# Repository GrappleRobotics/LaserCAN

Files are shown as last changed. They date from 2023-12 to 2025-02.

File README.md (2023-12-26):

# Grapple LaserCAN
Welcome to the open-source repository for the Grapple LaserCAN! That's right, everything's open source from the board files to the firmware.

**[Buy Here](https://grapplerobotics.au/)**

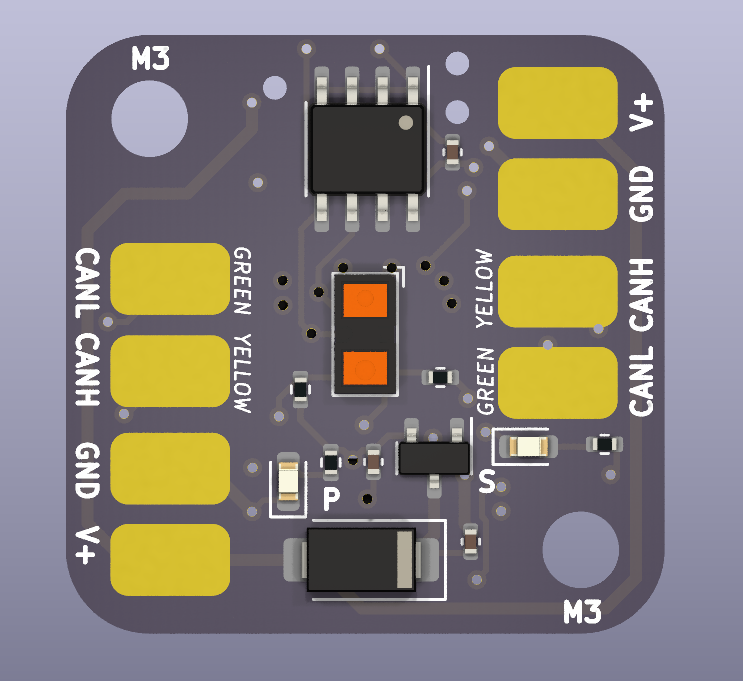
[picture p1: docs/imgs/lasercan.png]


## [Looking for docs?](docs/getting-started.md)

## Project Directories
- [LaserCAN-Board](LaserCAN-Board) is the KiCAD project that contains the LaserCAN board files. 
- [lasercan-common](lasercan-common) are common libraries used between the firmware and bootloader.
- [lasercan-bootloader](lasercan-bootloader) is the CAN bootloader for the LaserCAN, written in Rust. The bootloader allows for over-the-air (or over-the-CAN, rather) firmware updates.
- [lasercan-firmware](lasercan-firmware) is the actual firmware for the LaserCAN, including sensor measurement and acquisition, CAN communication, and everything else it does!

## Loading your own firmware
If you want to load your own firmware onto the LaserCAN, clone this repository and make your changes to `lasercan-firmware`. You can flash this image to the board by running `python build.py firmware` and flashing the `target/lasercan-firmware-update-VERSION.grplfw` file using GrappleHook.
**NOTE: Be careful about what firmware you flash - custom firmware may brick the firmware update process if you don't have a ST-Link probe handy.**

## Flashing a new bootloader
If you for whatever reason need to flash a new bootloader, or if a custom firmware has crashed and the watchdog hasn't picked it up, you can flash a new bootloader and firmware by running `python build.py flash`. This requires an ST-Link v2 compatible probe and a TagConnect TC-2050-NL cable to connect to the debug pads on the bottom of the LaserCAN.

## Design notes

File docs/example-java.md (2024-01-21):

# LaserCAN - FRC Example (Java)

## Install the Vendor Library:
In VSCode, hit CTRL+SHIFT+P and select "WPILib: Manage Vendor Libraries".  Select "Install new libraries (offline)" and paste the following URL: https://storage.googleapis.com/grapple-frc-maven/libgrapplefrc2024.json

## Use it!
```java
package frc.robot;

import au.grapplerobotics.LaserCan;
import au.grapplerobotics.ConfigurationFailedException;
import edu.wpi.first.wpilibj.TimedRobot;

public class Robot extends TimedRobot {
  private LaserCan lc;

  @Override
  public void robotInit() {
    lc = new LaserCan(0);
    // Optionally initialise the settings of the LaserCAN, if you haven't already done so in GrappleHook
    try {
      lc.setRangingMode(LaserCan.RangingMode.SHORT);
      lc.setRegionOfInterest(new LaserCan.RegionOfInterest(8, 8, 16, 16));
      lc.setTimingBudget(LaserCan.TimingBudget.TIMING_BUDGET_33MS);
    } catch (ConfigurationFailedException e) {
      System.out.println("Configuration failed! " + e);
    }
  }

  @Override
  public void robotPeriodic() {
    LaserCan.Measurement measurement = lc.getMeasurement();
    if (measurement != null && measurement.status == LaserCan.LASERCAN_STATUS_VALID_MEASUREMENT) {
      System.out.println("The target is " + measurement.distance_mm + "mm away!");
    } else {
      System.out.println("Oh no! The target is out of range, or we can't get a reliable measurement!");
      // You can still use distance_mm in here, if you're ok tolerating a clamped value or an unreliable measurement.
    }
  }

  @Override
  public void autonomousInit() {}

  @Override
  public void autonomousPeriodic() {}

  @Override
  public void teleopInit() {}

  @Override
  public void teleopPeriodic() {}

  @Override
  public void disabledInit() {}

  @Override
  public void disabledPeriodic() {}

  @Override
  public void testInit() {}

  @Override
  public void testPeriodic() {}
}
```

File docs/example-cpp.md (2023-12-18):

# LaserCAN - FRC Example (C++)

## Install the Vendor Library:
In VSCode, hit CTRL+SHIFT+P and select "WPILib: Manage Vendor Libraries".  Select "Install new libraries (offline)" and paste the following URL: https://storage.googleapis.com/grapple-frc-maven/libgrapplefrc2024.json

## Use it!
`Robot.h`

```c++
#pragma once

#include <frc/TimedRobot.h>
#include <grpl/LaserCan.h>

class Robot : public frc::TimedRobot {
 public:
  void RobotInit() override;
  void RobotPeriodic() override;

  void AutonomousInit() override;
  void AutonomousPeriodic() override;

  void TeleopInit() override;
  void TeleopPeriodic() override;

  void DisabledInit() override;
  void DisabledPeriodic() override;

  void TestInit() override;
  void TestPeriodic() override;
 private:
  grpl::LaserCan *lc;
};
```

`Robot.cpp`

```c++
#include "Robot.h"
#include <iostream>

void Robot::RobotInit() {
  lc = new grpl::LaserCan(0);
    // Optionally initialise the settings of the LaserCAN, if you haven't already done so in GrappleHook
  lc->set_ranging_mode(grpl::LaserCanRangingMode::Long);
  lc->set_timing_budget(grpl::LaserCanTimingBudget::TimingBudget100ms);
  lc->set_roi(grpl::LaserCanROI{ 8, 8, 16, 16 });
}

void Robot::RobotPeriodic() {
  std::optional<grpl::LaserCanMeasurement> measurement = lc->get_measurement();
  if (measurement.has_value() && measurement.value().status == grpl::LASERCAN_STATUS_VALID_MEASUREMENT) {
    std::cout << "The target is " << measurement.value().distance_mm << "mm away!" << std::endl;
  } else {
    std::cout << "Oh no! The target is out of range, or we can't get a reliable measurement!" << std::endl;
    // You can still use distance_mm in here, if you're ok tolerating a clamped value or an unreliable measurement.
  }
}

void Robot::AutonomousInit() {}
void Robot::AutonomousPeriodic() {}

void Robot::TeleopInit() {}
void Robot::TeleopPeriodic() {}

void Robot::DisabledInit() {}
void Robot::DisabledPeriodic() {}

void Robot::TestInit() {}
void Robot::TestPeriodic() {}

#ifndef RUNNING_FRC_TESTS
int main() {
  return frc::StartRobot<Robot>();
}
#endif

```

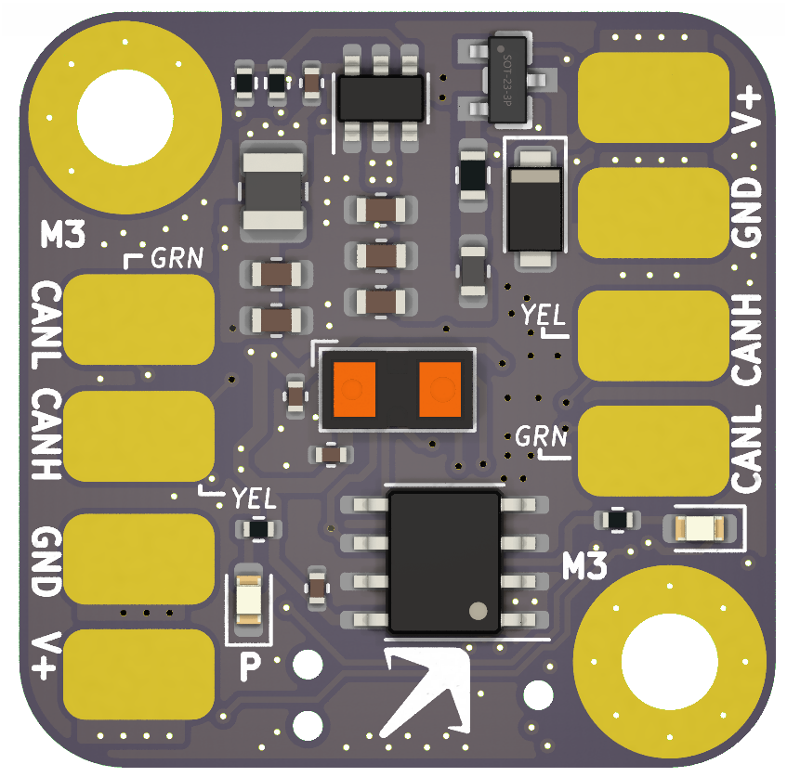
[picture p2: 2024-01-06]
docs/imgs/lasercan_rev4_transparent.png

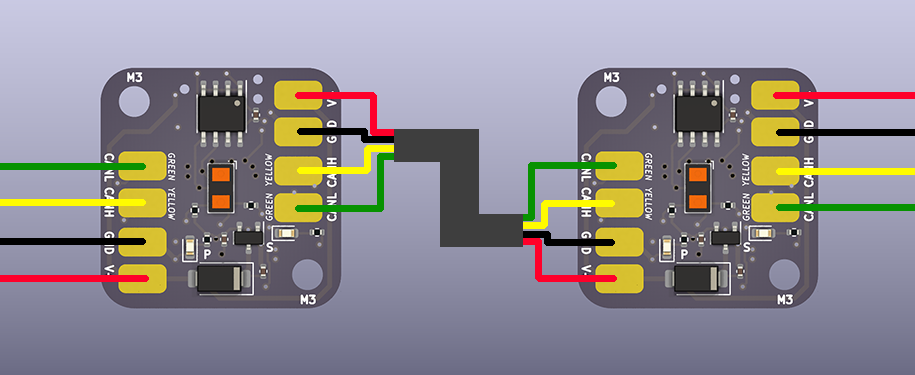
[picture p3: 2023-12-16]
docs/imgs/daisychain.png

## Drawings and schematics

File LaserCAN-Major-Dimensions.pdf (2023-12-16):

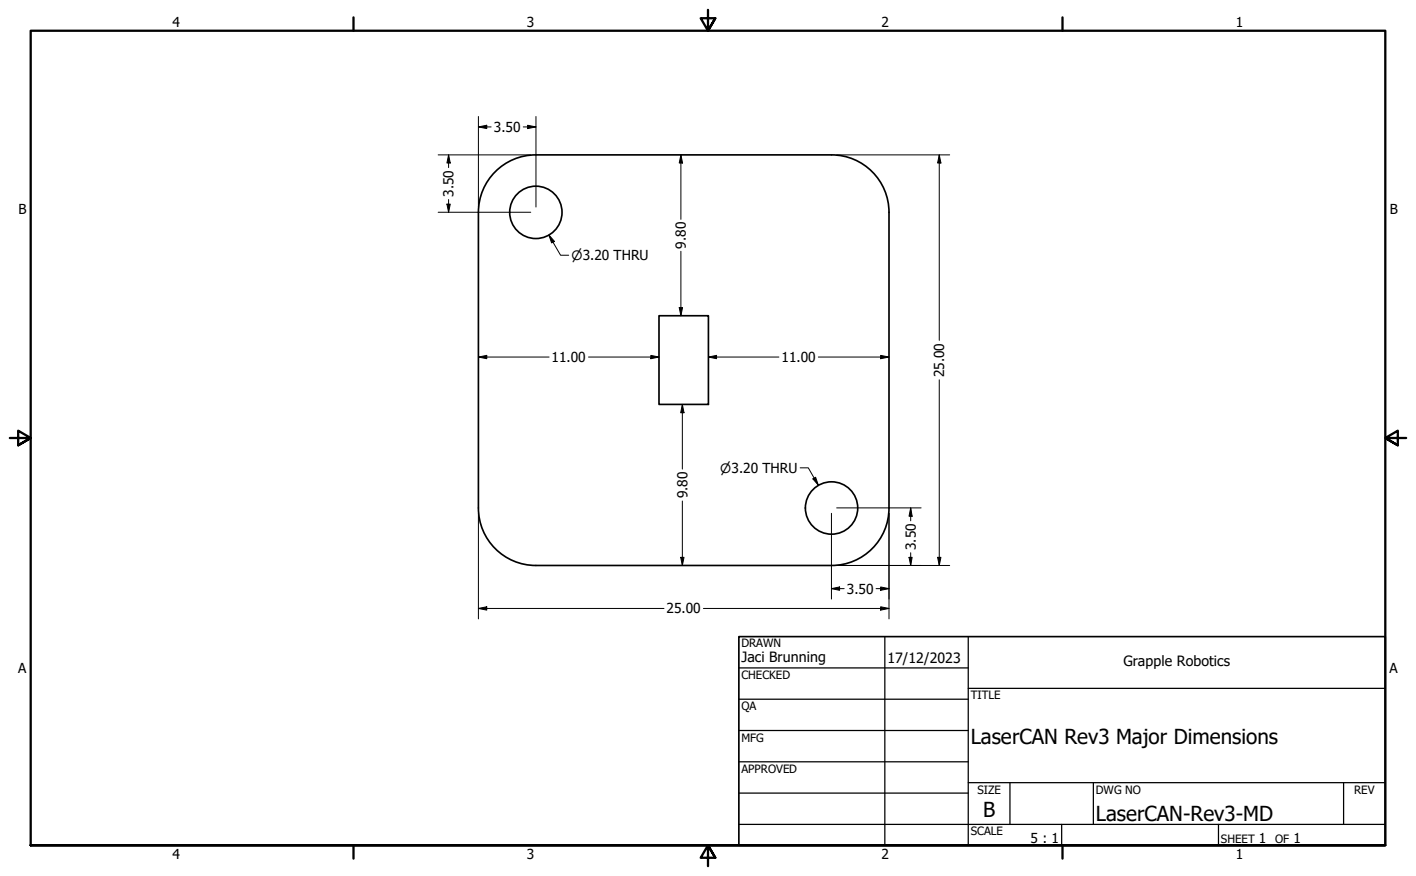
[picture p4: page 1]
⌀3.20 THRU

DRAWN Jaci Brunning | 17/12/2023 | Grapple Robotics

CHECKED

TITLE
LaserCAN Rev3 Major Dimensions

MFG

APPROVED

SIZE B | DWG NO LaserCAN-Rev3-MD | REV

SCALE 5 : 1 | | SHEET 1 OF 1

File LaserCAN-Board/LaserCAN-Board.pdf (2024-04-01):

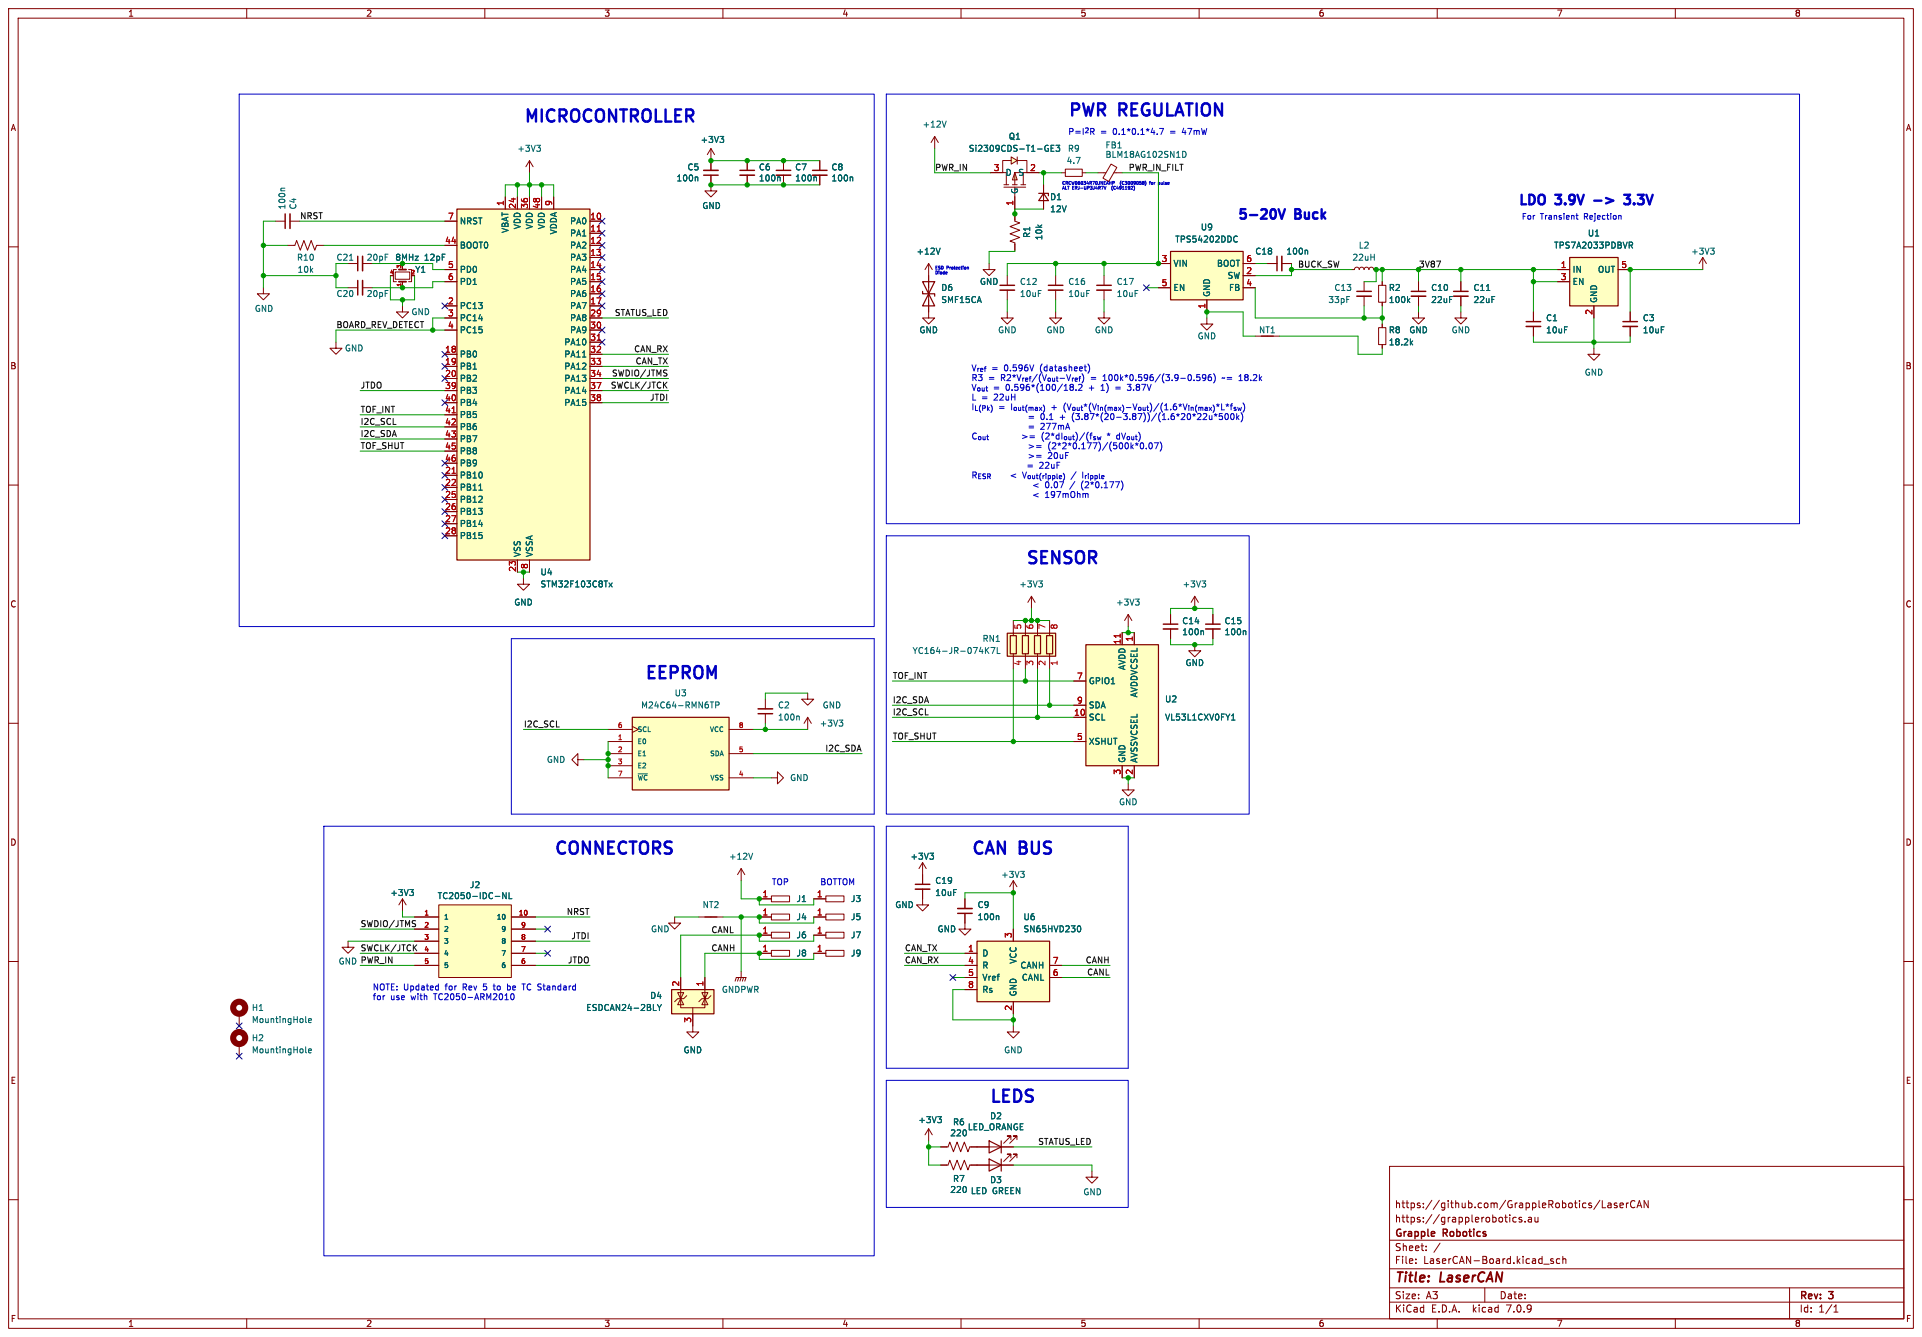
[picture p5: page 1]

For Transient Rejection CAN BUS

NOTE: Updated for Rev 5 to be TC Standard

https://github.com/GrappleRobotics/LaserCAN
https://grapplerobotics.au

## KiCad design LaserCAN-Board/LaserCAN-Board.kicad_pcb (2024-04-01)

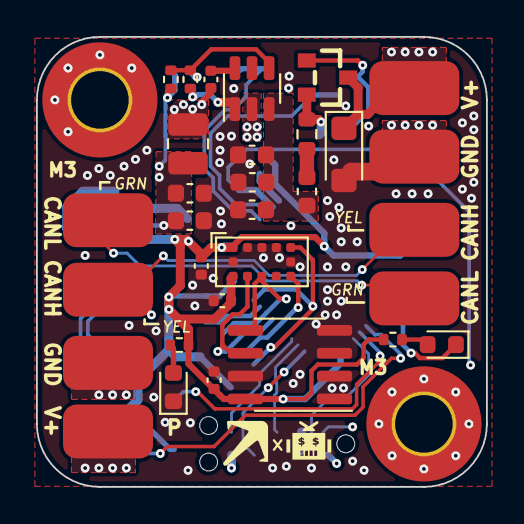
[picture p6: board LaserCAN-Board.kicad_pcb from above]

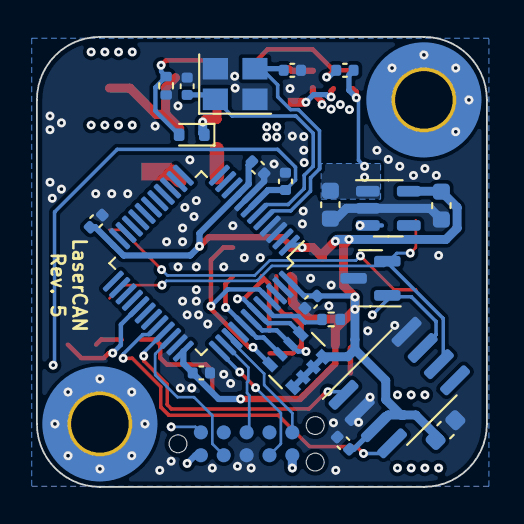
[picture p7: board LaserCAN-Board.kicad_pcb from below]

Board: 4 copper layers, 25.0 x 25.0 mm, 57 parts (22 on the bottom side), 32 nets.

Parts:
C1, C3, C12, C16, C17, C19: 10uF; C_0603_1608Metric
C2, C4, C5, C6, C7, C8, C9, C14, C15, C18: 100n; C_0402_1005Metric
C10, C11: 22uF; C_0603_1608Metric
C13: 33pF; C_0402_1005Metric
C20, C21: 20pF; C_0402_1005Metric
D1: 12V; D_SOD-523
D2: LED_ORANGE; LED_0603_1608Metric
D3: LED GREEN; LED_0603_1608Metric
D4: ESDCAN24-2BLY; SOT-23
D6: SMF15CA; D_SMF
FB1: BLM18AG102SN1D; L_0603_1608Metric
H1, H2: MountingHole; MountingHole_3.2mm_M3_Pad_TopBottom
J1, J3, J4, J5, J6, J7, J8, J9: Pad
J2: TC2050-IDC-NL; TAG-CONNECT_TC2050-IDC-NL
L2: 22uH; L_1008_2520Metric
NT1: NetTie_2; NetTie-2_SMD_Pad0.5mm
NT2: NetTie_2; NetTie-2_SMD_Pad2.0mm
Q1: Si2309CDS-T1-GE3; SOT-23_L2.9-W1.3-P1.90-LS2.4-BR
R1, R10: 10k; R_0402_1005Metric
R2: 100k; R_0402_1005Metric
R6, R7: 220; R_0402_1005Metric
R8: 18.2k; R_0402_1005Metric
R9: 4.7; R_0603_1608Metric
RN1: YC164-JR-074K7L; R_Array_Convex_4x0603
U1: TPS7A2033PDBVR; SOT-23-5
U2: VL53L1CXV0FY1; ST_VL53L1x
U3: M24C64-RMN6TP; SOIC-8_3.9x4.9mm_P1.27mm
U4: STM32F103C8Tx; LQFP-48_7x7mm_P0.5mm
U6: SN65HVD230; SOIC-8_3.9x4.9mm_P1.27mm
U9: TPS54202DDC; SOT-23-6
Y1: 8MHz 12pF; Crystal_SMD_3225-4Pin_3.2x2.5mm

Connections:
+3V3: C2.1, C3.1, C5.2, C6.1, C7.1, C8.1, C9.2, C14.1, C15.1, C19.1, J2.1, R6.1, R7.1, RN1.5 (R4.2), RN1.6 (R3.2), RN1.7 (R2.2), RN1.8 (R1.2), U1.5 (OUT), U2.1 (AVDDVCSEL), U2.11 (AVDD), U3.8 (VCC), U4.1 (VBAT), U4.9 (VDDA), U4.24 (VDD), U4.36 (VDD), U4.48 (VDD), U6.3 (VCC)
+12V: D6.1 (A1), J1.1, J2.5, J3.1, Q1.3 (D)
/3V87: C1.1, C10.1, C11.1, C13.1, L2.2, R2.1, U1.1 (IN), U1.3 (EN)
/BUCK_SW: C18.2, L2.1, U9.2 (SW)
/CANH: D4.1 (K), J8.1, J9.1, U6.7 (CANH)
/CANL: D4.2 (K), J6.1, J7.1, U6.6 (CANL)
/CAN_RX: U4.32 (PA11), U6.4 (R)
/CAN_TX: U4.33 (PA12), U6.1 (D)
/I2C_SCL: RN1.2 (R2.1), U2.10 (SCL), U3.6 (SCL), U4.42 (PB6)
/I2C_SDA: RN1.1 (R1.1), U2.9 (SDA), U3.5 (SDA), U4.43 (PB7)
/JTDI: J2.8, U4.38 (PA15)
/JTDO: J2.6, U4.39 (PB3)
/NRST: C4.2, J2.10, U4.7 (NRST)
/PWR_IN_FILT: C12.1, C16.1, C17.1, FB1.2, U9.3 (VIN)
/STATUS_LED: D2.1 (K), U4.29 (PA8)
/SWCLK/JTCK: J2.4, U4.37 (PA14)
/SWDIO/JTMS: J2.2, U4.34 (PA13)
/TOF_INT: RN1.3 (R3.1), U2.7 (GPIO1), U4.41 (PB5)
/TOF_SHUT: RN1.4 (R4.1), U2.5 (XSHUT), U4.45 (PB8)
GND: C1.2, C2.2, C3.2, C4.1, C5.1, C6.2, C7.2, C8.2, C9.1, C10.2, C11.2, C12.2, C14.2, C15.2, C16.2, C17.2, C19.2, C20.1, C21.1, D3.1 (K), D4.3 (A), D6.2 (A2), J2.3, NT1.2, NT2.1, R1.1, R10.1, U1.2 (GND), U2.2 (AVSSVCSEL), U2.3 (GND), U2.4 (GND), U2.6 (GND), U2.12 (GND), U3.1 (E0), U3.2 (E1), U3.3 (E2), U3.4 (VSS), U3.7 (~WC), U4.3 (PC14), U4.4 (PC15), U4.8 (VSSA), U4.23 (VSS), U4.35 (VSS), U4.47 (VSS), U6.2 (GND), U6.8 (Rs), U9.1 (GND), Y1.2, Y1.4
GNDPWR: J4.1, J5.1, NT2.2
unnamed: D1.2 (A), Q1.1 (G), R1.2
unnamed: D1.1 (K), Q1.2 (S), R9.1
unnamed: D2.2 (A), R6.2
unnamed: D3.2 (A), R7.2
unnamed: FB1.1, R9.2
unnamed: NT1.1, R8.2
unnamed: R10.2, U4.44 (BOOT0)
unnamed: C21.2, U4.5 (PD0), Y1.3
unnamed: C20.2, U4.6 (PD1), Y1.1
unnamed: C18.1, U9.6 (BOOT)
unnamed: C13.2, R2.2, R8.1, U9.4 (FB)

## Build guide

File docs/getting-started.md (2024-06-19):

# Getting Started with LaserCAN
Getting Started with LaserCAN is easy! Follow this guide and you'll be using your sensor in no time!

## 1. Connect Power
**IMPORTANT:** Double check the FRC Rule Manual for wire gauges, PDP/PDH output selection, etc.

### Direct
To wire up your LaserCAN, connect V+ to the 6V (PWM) or 5V (DIO) source on your RoboRIO, and GND to any Ground pin on the RoboRIO.

### Daisy-Chain
Alternatively, you can power the LaserCAN from another LaserCAN by connecting the V+ pads together, and likewise for the GND pads. **DO NOT** Daisy-Chain more than 8 LaserCANs in one chain!

## 2. Connect CAN
Next, connect the CANH and CANL pads of the LaserCAN to your robot's CAN bus. This can be done in one of three ways:

### Pass-Through
Insert the LaserCAN in an existing CAN line by connecting both sides of the LaserCAN's CAN pads, "passing through" the connection to downstream devices.

### Star
Alternatively, branch off from an existing CAN connection, forming a new branch that can be connected to one side of the LaserCAN. If connecting in this manner, ensure the stub length is short (i.e. a short branch).

### Star + Pass-Through
If you have more than one LaserCAN, you can use the Star method to connect the first LaserCAN, and connect the rest through passthrough, starting at the first LaserCAN's unoccupied pads. Ensure the total stub length is also short, less than 2 meters for 1Mbps CAN 2.0B.

## 3. Power on your LaserCAN
Power on your robot to power on the LaserCAN. The orange LED should blink rapidly for 2-3 seconds before turning off. If the orange LED remains on, your LaserCAN may require a firmware update.

## 4. Download and Install GrappleHook
Download the latest version of GrappleHook for your platform here: https://github.com/GrappleRobotics/GrappleHook/releases

*Tip: If you're on windows, select the asset ending in .msi*

## 5. Run GrappleHook
Connect your RoboRIO over a USB cable, and open GrappleHook. Select RoboRIO, and hit "Connect"

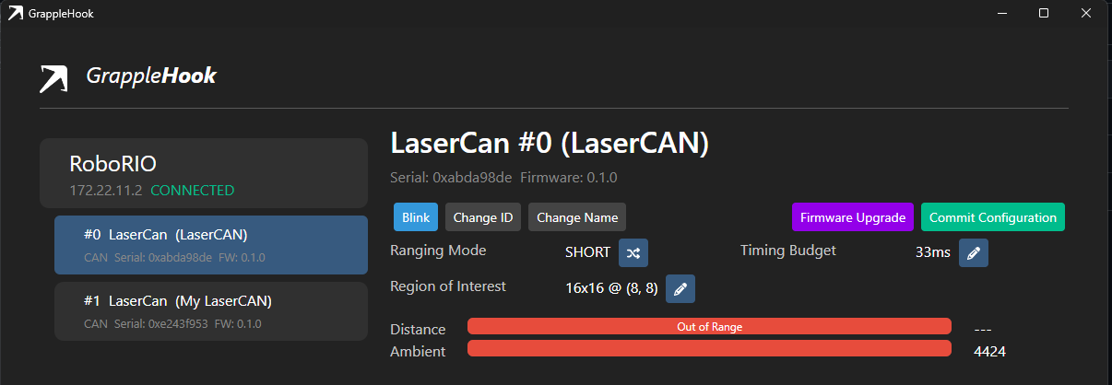
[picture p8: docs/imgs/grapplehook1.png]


## 6. Set the CAN ID
In GrappleHook, select "Change ID" and set a new CAN ID for your LaserCAN. Choose something unique from other LaserCANs, otherwise they'll conflict!

## 7. Install the libgrapplefrc Vendor Library
In VSCode, hit CTRL+SHIFT+P and select "WPILib: Manage Vendor Libraries".  Select "Install new libraries (online)" and paste the following URL: https://storage.googleapis.com/grapple-frc-maven/libgrapplefrc2024.json

## 8. Use LaserCAN!
See one of our examples: 
- [Java](example-java.md)
- [C++](example-cpp.md)

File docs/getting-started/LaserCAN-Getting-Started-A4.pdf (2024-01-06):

# Getting Started with LaserCAN

# 1. Remove Protective Film

Remove the protective fi lm from the laser sensor in the centre of the LaserCAN.

# 2. Connect Power

While your robot is powered o , wire the V+ and GND to RoboRIO 5V or 6V rails, found on the PWM and DIO headers, or to the PDP / PDH Fused Channels. Alternatively, daisy-chain power from another LaserCAN device (up to 8).

# 3. Connect CAN

Solder your Green and Yellow CAN wires to CANL and CANH on the LaserCAN respectively. Optionally, daisy chain other CAN devices (data only).

# 4. Power On

Turn your robot on. You should see the LaserCAN’s yellow LED blink briefl y.

# 5. Confi gure the LaserCAN

Download GrappleHook from https://grapplerobotics.au/grapplehook/ and install. Launch GrappleHook and connect to your RoboRIO to set a CAN ID and name, as well as modify LaserCAN settings.

# 6. Get the Vendor Dependency

Follow the instructions at https://grapplerobotics.au/product/lasercan/ to integrate

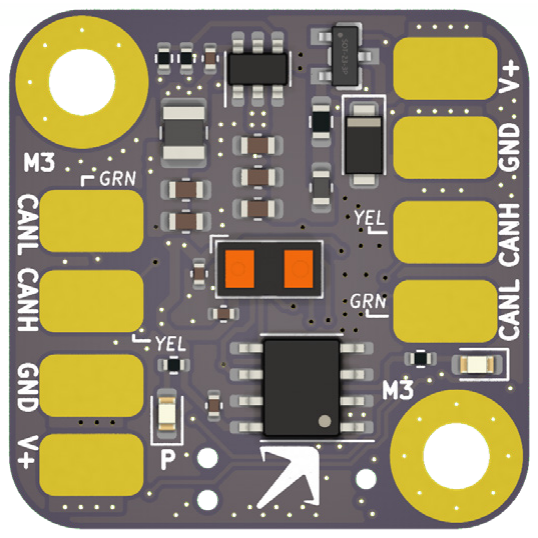
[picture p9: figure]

into your FRC code. | Thank you for your purchase! Need help? Find more info at https://grapplerobotics.au

# Getting Started with LaserCAN

# 1. Remove Protective Film

Remove the protective fi lm from the laser sensor in the centre of the LaserCAN.

# 2. Connect Power

While your robot is powered o , wire the V+ and GND to RoboRIO 5V or 6V rails, found on the PWM and DIO headers, or to the PDP / PDH Fused Channels. Alternatively, daisy-chain power from another LaserCAN device (up to 8).

# 3. Connect CAN

Solder your Green and Yellow CAN wires to CANL and CANH on the LaserCAN respectively. Optionally, daisy chain other CAN devices (data only).

# 4. Power On

Turn your robot on. You should see the LaserCAN’s yellow LED blink briefl y.

# 5. Confi gure the LaserCAN

Download GrappleHook from https://grapplerobotics.au/grapplehook/ and install. Launch GrappleHook and connect to your RoboRIO to set a CAN ID and name, as well as modify LaserCAN settings.

# 6. Get the Vendor Dependency

Follow the instructions at https://grapplerobotics.au/product/lasercan/ to integrate

into your FRC code. | Thank you for your purchase! Need help? Find more info at https://grapplerobotics.au

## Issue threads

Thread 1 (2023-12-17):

PDF of schematic?

marshallmassengill, 2023-12-17:
Really minor but can you include a pdf of the schematic in the repo?

JaciBrunning, 2023-12-17:
done! https://github.com/GrappleRobotics/LaserCAN/blob/master/LaserCAN-Board/LaserCAN-Board.pdf

Closed 2023-12-17.

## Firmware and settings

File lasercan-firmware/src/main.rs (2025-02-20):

#![no_main]
#![no_std]

extern crate alloc;

use core::{mem::MaybeUninit, sync::atomic::AtomicU32};

use alloc::{format, collections::VecDeque};
use bxcan::{filter::Mask32, ExtendedId};
use embedded_alloc::Heap;
use grapple_lasercan::{grapple_frc_msgs::{binmarshal::AsymmetricCow, grapple::{device_info::GrappleModelId, errors::{GrappleResult, GrappleError}, lasercan}}, Sensor, Watchdog, SysTick, DropToBootloader, CanBus, InputOutput};
use lasercan_common::bootutil::{FIRMWARE_MAGIC, feed_watchdog};
use panic_halt as _;
use stm32f1xx_hal::{pac::{IWDG, CAN1, Interrupt}, flash, can::Can, gpio::{ErasedPin, Output}};

#[link_section = ".metadata.magic"]
#[no_mangle]
pub static META_MAGIC: u32 = FIRMWARE_MAGIC;

#[link_section = ".metadata.version"]
#[no_mangle]
pub static META_VERSION: &'static str = env!("CARGO_PKG_VERSION");

#[link_section = ".metadata.model_id"]
#[no_mangle]
pub static META_MODEL_ID: GrappleModelId = GrappleModelId::LaserCan;

#[global_allocator]
static HEAP: Heap = Heap::empty();
const HEAP_SIZE: usize = 4096;

fn heap_init() {
  static mut HEAP_MEM: [MaybeUninit<u8>; HEAP_SIZE] = [MaybeUninit::uninit(); HEAP_SIZE];
  unsafe { HEAP.init(HEAP_MEM.as_ptr() as usize, HEAP_SIZE) }
}

static TIME_MS: AtomicU32 = AtomicU32::new(0);

macro_rules! convert_sensor_err {
  ($ex:expr) => {
    $ex.map_err(|e| GrappleError::Generic(AsymmetricCow(alloc::borrow::Cow::Owned(format!("{:?}", e)))))
  }
}

pub struct VL53Sensor<E: core::fmt::Debug, T: vl53l1x_uld::comm::Write<Error = E> + vl53l1x_uld::comm::Read<Error = E>> {
  pub sensor: vl53l1x_uld::VL53L1X<T>,
  pub mode: lasercan::LaserCanRangingMode,
  pub roi: lasercan::LaserCanRoi,
  pub budget: lasercan::LaserCanTimingBudget,
}

impl <E: core::fmt::Debug, T: vl53l1x_uld::comm::Write<Error = E> + vl53l1x_uld::comm::Read<Error = E>> VL53Sensor<E, T> {
  pub fn new(sensor: vl53l1x_uld::VL53L1X<T>) -> Self {
    Self {
      sensor,
      mode: lasercan::LaserCanRangingMode::Short,
      roi: lasercan::LaserCanRoi { x: lasercan::LaserCanRoiU4(8), y: lasercan::LaserCanRoiU4(8), w: lasercan::LaserCanRoiU4(16), h: lasercan::LaserCanRoiU4(16) },
      budget: lasercan::LaserCanTimingBudget::TB33ms,
    }
  }

  pub fn init(&mut self) -> GrappleResult<'static, ()> {
    convert_sensor_err!(self.sensor.init(vl53l1x_uld::IOVoltage::Volt2_8))?;
    self.set_ranging_mode(self.mode.clone())?;
    self.set_roi(self.roi.clone())?;
    self.set_timing_budget_ms(self.budget.clone())?;
    self.start_ranging()?;
    Ok(())
  }
}

impl <E: core::fmt::Debug, T: vl53l1x_uld::comm::Write<Error = E> + vl53l1x_uld::comm::Read<Error = E>> Sensor for VL53Sensor<E, T> {
  fn data_ready(&mut self) -> GrappleResult<'static, bool> {
    convert_sensor_err!(self.sensor.is_data_ready())
  }

  fn get_result(&mut self) -> GrappleResult<'static, lasercan::LaserCanMeasurement> {
    let result = convert_sensor_err!(self.sensor.get_result())?;
    Ok(lasercan::LaserCanMeasurement {
      status: result.status as u8,
      distance_mm: result.distance_mm,
      ambient: result.ambient,
      mode: self.mode.clone(),
      budget: self.budget.clone(),
      roi: self.roi.clone(),
    })
  }

  fn stop_ranging(&mut self) -> GrappleResult<'static, ()> {
    convert_sensor_err!(self.sensor.stop_ranging())
  }

  fn start_ranging(&mut self) -> GrappleResult<'static, ()> {
    convert_sensor_err!(self.sensor.start_ranging())
  }

  fn set_ranging_mode(&mut self, mode: lasercan::LaserCanRangingMode) -> GrappleResult<'static, ()> {
    convert_sensor_err!(self.sensor.set_distance_mode(match mode {
      lasercan::LaserCanRangingMode::Short => vl53l1x_uld::DistanceMode::Short,
      lasercan::LaserCanRangingMode::Long => vl53l1x_uld::DistanceMode::Long,
    }))?;
    self.mode = mode;
    Ok(())
  }

  fn set_roi(&mut self, roi: lasercan::LaserCanRoi) -> GrappleResult<'static, ()> {
    convert_sensor_err!(self.sensor.set_roi(vl53l1x_uld::roi::ROI::new(roi.w.0 as u16, roi.h.0 as u16)))?;
    convert_sensor_err!(self.sensor.set_roi_center(vl53l1x_uld::roi::ROICenter::new(roi.x.0, roi.y.0)))?;
    self.roi = roi;
    Ok(())
  }

  fn set_timing_budget_ms(&mut self, budget: lasercan::LaserCanTimingBudget) -> GrappleResult<'static, ()> {
    convert_sensor_err!(self.sensor.set_timing_budget_ms(budget.clone() as u8 as u16))?;
    self.budget = budget;
    Ok(())
  }
}

pub struct WatchdogImpl {
  pub watchdog: IWDG
}

impl Watchdog for WatchdogImpl {
  fn feed(&mut self) {
    feed_watchdog(&mut self.watchdog);
  }
}

pub struct SysTickImpl;

impl SysTick for SysTickImpl {
  fn time(&self) -> u32 {
    TIME_MS.load(core::sync::atomic::Ordering::Relaxed)
  }
}

pub struct DropToBootloaderImpl {
  pub flash: flash::Parts
}

impl DropToBootloader for DropToBootloaderImpl {
  fn drop_to_bootloader(&mut self) {
    let mut writer = self.flash.writer(flash::SectorSize::Sz1K, flash::FlashSize::Sz64K);
    lasercan_common::bootutil::start_field_upgrade(&mut writer);
  }
}

pub struct InputOutputImpl {
  pub led: ErasedPin<Output>
}

impl InputOutput for InputOutputImpl {
  fn set_led(&mut self, value: bool) {
    self.led.set_state(match value {
      true => stm32f1xx_hal::gpio::PinState::Low,
      false => stm32f1xx_hal::gpio::PinState::High,
    });
  }

  fn toggle_led(&mut self) {
    self.led.toggle();
  }
}

pub struct CanBusImpl {
  pub can: bxcan::Can<Can<CAN1>>,
  pub queue: VecDeque<bxcan::Frame>,
  pub next_bank: u8
}

impl CanBusImpl {
  pub fn new(can_bus: bxcan::Can<Can<CAN1>>) -> Self {
    Self { can: can_bus, queue: VecDeque::with_capacity(64), next_bank: 0 }
  }
}

impl CanBus for CanBusImpl {
  const MAX_MSG_SIZE: usize = 8;

  fn subscribe(&mut self, id: grapple_lasercan::grapple_frc_msgs::MessageId, mask: grapple_lasercan::grapple_frc_msgs::MessageId) {
    unsafe {
      self.can.modify_filters()
        .enable_bank(self.next_bank, bxcan::Fifo::Fifo0, Mask32::frames_with_ext_id(
          ExtendedId::new_unchecked(id.into()),
          ExtendedId::new_unchecked(mask.into())
        ));
    }
    
    self.next_bank += 1;
  }

  fn enqueue_msg(&mut self, id: grapple_lasercan::grapple_frc_msgs::MessageId, buf: &[u8]) {
    self.queue.push_back(bxcan::Frame::new_data(ExtendedId::new(id.into()).unwrap(), bxcan::Data::new(buf).unwrap()));
    rtic::pend(Interrupt::USB_HP_CAN_TX);
  }
}

#[rtic::app(device = stm32f1xx_hal::pac, peripherals = true)]
mod app {
  use core::{marker::PhantomData, arch::asm};

  use bxcan::Interrupts;
  use grapple_lasercan::LaserCANImpl;
  use shared_bus::new_cortexm;
  use grapple_m24c64::M24C64;
  use lasercan_common::bootutil::feed_watchdog;
  use stm32f1xx_hal::{prelude::*, flash::FlashExt, pac::{TIM1, TIM2, I2C1, Interrupt}, timer::{self, CounterMs, CounterHz}, gpio::{Alternate, OpenDrain}, can::Can, i2c::{Mode, BlockingI2c}};

  use crate::{heap_init, META_VERSION, WatchdogImpl, SysTickImpl, DropToBootloaderImpl, CanBusImpl, InputOutputImpl};

  pub type Impl = LaserCANImpl<crate::WatchdogImpl, crate::SysTickImpl, crate::DropToBootloaderImpl, crate::CanBusImpl, crate::InputOutputImpl>;

  #[shared]
  struct SharedResources {
    lasercan_impl: Impl,
  }
  
  #[local]
  struct LocalResources {
    led_timer: CounterMs<TIM1>,
    status_timer: CounterHz<TIM2>,
  }

  #[init]
  fn init(mut ctx: init::Context) -> (SharedResources, LocalResources, init::Monotonics) {
    let mut gpioa = ctx.device.GPIOA.split();
    let mut gpiob = ctx.device.GPIOB.split();
    let mut gpioc = ctx.device.GPIOC.split();
    let mut afio = ctx.device.AFIO.constrain();

    let pc15_board_rev_detect = gpioc.pc15.into_pull_up_input(&mut gpioc.crh);
    let pc14_board_rev_detect = gpioc.pc14.into_pull_up_input(&mut gpioc.crh);
    
    let mut flash = ctx.device.FLASH.constrain();

    let clocks = match pc15_board_rev_detect.is_low() {
      false => {
        // Rev 3 or Earlier (w/o Crystal)
        ctx.device.RCC.constrain().cfgr.freeze(&mut flash.acr)
      },
      true => {
        // Rev 4 or Later (w/ Crystal)
        ctx.device.RCC.constrain().cfgr.use_hse(8.MHz()).freeze(&mut flash.acr)
      }
    };

    feed_watchdog(&mut ctx.device.IWDG);

    let mut tof_shut_pin = match pc14_board_rev_detect.is_low() {
      false => {
        // Rev 4 or earlier
        let (_pa15, _pb3, pb4) = afio.mapr.disable_jtag(gpioa.pa15, gpiob.pb3, gpiob.pb4);
        pb4.into_push_pull_output(&mut gpiob.crl).erase()
      },
      true => {
        // Rev 5 or later
        gpiob.pb8.into_push_pull_output(&mut gpiob.crh).erase()
      }
    };
    tof_shut_pin.set_low();

    /* TIMER INIT */
    let mut systick = ctx.core.SYST.counter_us(&clocks);
    systick.start(100.millis()).unwrap();
    systick.listen(timer::SysEvent::Update);

    /* LED INIT */

    let mut status_led = gpioa.pa8.into_push_pull_output(&mut gpioa.crh);
    status_led.set_low();

    let mut led_timer = ctx.device.TIM1.counter_ms(&clocks);
    led_timer.start(50.millis()).unwrap();
    led_timer.listen(timer::Event::Update);

    heap_init();

    /* I2C INIT */
    let scl = gpiob.pb6.into_alternate_open_drain(&mut gpiob.crl);
    let sda = gpiob.pb7.into_alternate_open_drain(&mut gpiob.crl);
    let i2c = BlockingI2c::i2c1(
      ctx.device.I2C1,
      (scl, sda),
      &mut afio.mapr,
      Mode::Fast { frequency: 400.kHz(), duty_cycle: stm32f1xx_hal::i2c::DutyCycle::Ratio16to9 },
      clocks,
      1000,
      5,
      1000,
      1000
    );
    
    // This is ugly, but what can you do?
    let i2c_bus = new_cortexm!(BlockingI2c<I2C1, ( stm32f1xx_hal::gpio::gpiob::PB6<Alternate<OpenDrain>>, stm32f1xx_hal::gpio::gpiob::PB7<Alternate<OpenDrain>> )> = i2c).unwrap();
    
    /* CAN INIT */
    
    let can = Can::new(ctx.device.CAN1, ctx.device.USB);
    let rx = gpioa.pa11.into_floating_input(&mut gpioa.crh);
    let tx = gpioa.pa12.into_alternate_push_pull(&mut gpioa.crh);
    
    can.assign_pins((tx, rx), &mut afio.mapr);
    
    let mut can_bus = bxcan::Can::builder(can)
      .set_bit_timing(0x0005_0000)
      .leave_disabled();
      
    can_bus.enable_interrupts(Interrupts::TRANSMIT_MAILBOX_EMPTY | Interrupts::FIFO0_MESSAGE_PENDING);
    nb::block!(can_bus.enable_non_blocking()).unwrap();
    
    let mut status_timer = ctx.device.TIM2.counter_hz(&clocks);
    status_timer.start(50.Hz()).unwrap();
    status_timer.listen(timer::Event::Update);
    
    feed_watchdog(&mut ctx.device.IWDG);
    
    /* SENSOR INIT */
    let mut delay = ctx.device.TIM4.delay_ms(&clocks);

    tof_shut_pin.set_high();  // Enable sensor (shutdown is active low)
    
    // Give the sensor some time to start up
    delay.delay_ms(20u16);

    let mut sensor = alloc::boxed::Box::new(crate::VL53Sensor::new(vl53l1x_uld::VL53L1X::new(i2c_bus.acquire_i2c(), vl53l1x_uld::DEFAULT_ADDRESS)));
    if sensor.sensor.get_sensor_id().unwrap() != 0xEACC {
      panic!("Wrong Sensor ID!");
    }

    sensor.init().unwrap();

    // Give the sensor some more time
    delay.delay_ms(500u16);

    /* CONFIGURATION INIT */

    let config_delay = ctx.device.TIM3.delay_ms(&clocks);
    let eeprom = M24C64::new(i2c_bus.acquire_i2c(), 0b000);
    let config_marshal = grapple_config::m24c64::M24C64ConfigurationMarshal::new(eeprom, 0, config_delay, PhantomData::<grapple_lasercan::LaserCanConfiguration>);

    let lasercan_impl = LaserCANImpl::new(
      META_VERSION,
      lasercan_common::get_serial_hash(),
      WatchdogImpl { watchdog: ctx.device.IWDG },
      SysTickImpl,
      DropToBootloaderImpl { flash },
      CanBusImpl::new(can_bus),
      sensor,
      config_marshal,
      InputOutputImpl { led: status_led.erase() }
    ).unwrap();

    (
      SharedResources {
        lasercan_impl
      },
      LocalResources {
        led_timer,
        status_timer
      },
      init::Monotonics()
    )
  }

  #[task(binds = SysTick, priority=15, local=[])]
  fn systick_tick(_: systick_tick::Context) {
    crate::TIME_MS.fetch_add(100, core::sync::atomic::Ordering::Relaxed);
  }

  #[task(binds = TIM1_UP, priority = 1, shared = [lasercan_impl], local = [led_timer])]
  fn led_tick(mut ctx: led_tick::Context) {
    ctx.shared.lasercan_impl.lock(|i| i.on_led_tick());
    ctx.local.led_timer.clear_interrupt(timer::Event::Update);
  }

  #[task(binds = TIM2, priority = 15, shared = [lasercan_impl], local = [status_timer])]
  fn status_tick(mut ctx: status_tick::Context) {
    ctx.shared.lasercan_impl.lock(|i| i.on_status_tick());
    ctx.local.status_timer.clear_interrupt(timer::Event::Update);
  }

  #[task(binds = USB_HP_CAN_TX, priority = 13, shared = [lasercan_impl], local = [])]
  fn can_tx(mut ctx: can_tx::Context) {
    ctx.shared.lasercan_impl.lock(|i| {
      i.can.can.clear_tx_interrupt();

      while let Some(frame) = i.can.queue.front() {
        match i.can.can.transmit(&frame) {
          Ok(status) => match status.dequeued_frame() {
            Some(pending) => {
              i.can.queue.pop_front();
              i.can.queue.push_back(pending.clone());
              rtic::pend(Interrupt::USB_HP_CAN_TX);
            },
            None => {
              i.can.queue.pop_front();
            },
          },
          Err(nb::Error::WouldBlock) => break,
          Err(_) => unreachable!()
        }
      }

      // Don't let the queue grow too much, otherwise we enter a crash loop
      while i.can.queue.len() > 40 {
        i.can.queue.pop_front();
      }
    })
  }

  #[task(binds = USB_LP_CAN_RX0, shared = [lasercan_impl], local = [])]
  fn can_rx(mut ctx: can_rx::Context) {
    unsafe { asm!("nop") }
    ctx.shared.lasercan_impl.lock(|i| {
      loop {
        match i.can.can.receive() {
          Ok(frame) => match (frame.id(), frame.data()) {
            (bxcan::Id::Extended(ext), data) => {
              unsafe { asm!("nop") }
              
              let id = grapple_lasercan::grapple_frc_msgs::MessageId::from(ext.as_raw());
              let buf = data.map(|x| x.as_ref()).unwrap_or(&[]);

              i.on_can_message(id, buf);
            },
            _ => ()
          },
          Err(nb::Error::WouldBlock) => break,
          Err(nb::Error::Other(_)) => {}    // Ignore overrun errors
        }
      }
    });
    unsafe { asm!("nop") }
  }
}

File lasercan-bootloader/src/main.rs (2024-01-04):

#![no_main]
#![no_std]

use core::mem::MaybeUninit;

use embedded_alloc::Heap;
use grapple_frc_msgs::grapple::device_info::GrappleModelId;
use panic_halt as _;

extern crate alloc;

#[link_section = ".metadata.magic"]
#[no_mangle]
pub static META_MAGIC: u32 = 0xABCD1234;

#[link_section = ".metadata.version"]
#[no_mangle]
pub static META_BOOTLOADER_VERSION: &'static str = env!("CARGO_PKG_VERSION");

#[link_section = ".metadata.model_id"]
#[no_mangle]
pub static META_MODEL_ID: GrappleModelId = GrappleModelId::LaserCan;

#[global_allocator]
static HEAP: Heap = Heap::empty();
const HEAP_SIZE: usize = 4096;

fn heap_init() {
  static mut HEAP_MEM: [MaybeUninit<u8>; HEAP_SIZE] = [MaybeUninit::uninit(); HEAP_SIZE];
  unsafe { HEAP.init(HEAP_MEM.as_ptr() as usize, HEAP_SIZE) }
}

const WATCHDOG_COUNTER_ADDR: usize = 0x2000_0000;

#[rtic::app(device = stm32f1xx_hal::pac, peripherals = true)]
mod app {
  use alloc::collections::VecDeque;
  use bxcan::{ExtendedId, filter::Mask32, Interrupts, Rx0, Tx};
  use core::ops::Deref;
  use cortex_m::peripheral::SCB;
  use grapple_frc_msgs::{DEVICE_TYPE_FIRMWARE_UPGRADE, binmarshal::{Demarshal, rw::BitView}, grapple::{MANUFACTURER_GRAPPLE, GrappleBroadcastMessage, device_info::GrappleDeviceInfo, GrappleDeviceMessage, firmware::GrappleFirmwareMessage, TaggedGrappleMessage, fragments::{FragmentReassembler, FragmentReassemblerRx, FragmentReassemblerTx}}, DEVICE_ID_BROADCAST, DEVICE_TYPE_BROADCAST, ManufacturerMessage, MessageId};
  use lasercan_common::bootutil::{is_firmware_update_in_progress, is_user_code_present, FLASH_USER, FLASH_META_FIRMWARE_RESET_LOC};
  use stm32f1xx_hal::{prelude::*, watchdog::IndependentWatchdog, can::Can, pac::{CAN1, Interrupt}, gpio::{ErasedPin, Output}, flash::{self, FLASH_START}};
  use tiny_rng::Rand;

  use crate::{WATCHDOG_COUNTER_ADDR, heap_init, META_MODEL_ID, META_BOOTLOADER_VERSION};

  #[shared]
  struct SharedResources {
    can_tx_queue: VecDeque<bxcan::Frame>,
    status_led: ErasedPin<Output>,
    device_id: u8,
    #[lock_free]
    reassemble_tx: FragmentReassemblerTx
  }

  #[local]
  struct LocalResources {
    can_rx: Rx0<Can<CAN1>>,
    can_tx: Tx<Can<CAN1>>,
    reassemble_rx: FragmentReassemblerRx,
    flash: flash::Parts,
    offset: usize,
    rng: tiny_rng::Rng
  }

  #[init]
  fn init(mut ctx: init::Context) -> (SharedResources, LocalResources, init::Monotonics) {
    // Check if the reset was due to a watchdog timeout. After repeated timeouts, we'll 
    // drop to a firmware update prompt since it's clear the user program is not working
    // sufficiently.
    // We can't use RCC.reset_reason since that requires us to constrain the RCC, which 
    // we can't do yet. 
    let was_iwdg_reset = ctx.device.RCC.csr.read().iwdgrstf().is_reset();
    ctx.device.RCC.csr.modify(|_, w| w.rmvf().clear());

    let mut has_watchdog_timed_out = false;

    if !was_iwdg_reset {
      unsafe { core::ptr::write_volatile(WATCHDOG_COUNTER_ADDR as *mut u32, 0x00) }
    } else {
      let count = unsafe { core::ptr::read_volatile(WATCHDOG_COUNTER_ADDR as *mut u32) };
      unsafe { core::ptr::write_volatile(WATCHDOG_COUNTER_ADDR as *mut u32, count + 1) }

      if count >= 5 {
        has_watchdog_timed_out = true;
      }
    }

    // Jump to the user code if we don't need to be in the bootloader
    if is_user_code_present() && !is_firmware_update_in_progress() && !has_watchdog_timed_out {
      // Jump to user code, with watchdog
      let mut watchdog = IndependentWatchdog::new(ctx.device.IWDG);
      watchdog.start(3000.millis());
      watchdog.feed();

      jump_to_user_code(&mut ctx.core.SCB);
    }

    // We're in the bootloader :)

    let mut flash = ctx.device.FLASH.constrain();
    let clocks = ctx.device.RCC.constrain().cfgr.freeze(&mut flash.acr);
    
    let mut gpioa = ctx.device.GPIOA.split();

    let mut status_led = gpioa.pa8.into_push_pull_output(&mut gpioa.crh);
    status_led.set_low();

    heap_init();

    let mut afio = ctx.device.AFIO.constrain();

    let can = Can::new(ctx.device.CAN1, ctx.device.USB);
    let rx = gpioa.pa11.into_floating_input(&mut gpioa.crh);
    let tx = gpioa.pa12.into_alternate_push_pull(&mut gpioa.crh);

    can.assign_pins((tx, rx), &mut afio.mapr);

    let mut can_bus = bxcan::Can::builder(can)
      .set_bit_timing(0x0005_0000)
      .leave_disabled();

    unsafe {
      can_bus.modify_filters()
        .enable_bank(0, bxcan::Fifo::Fifo0, Mask32::frames_with_ext_id(
          ExtendedId::new_unchecked(MessageId { device_type: DEVICE_TYPE_FIRMWARE_UPGRADE, manufacturer: MANUFACTURER_GRAPPLE, api_class: 0x00, api_index: 0x00, device_id: 0x00 }.into()),
          ExtendedId::new_unchecked(MessageId { device_type: 0xFF, manufacturer: 0xFF, api_class: 0x00, api_index: 0x00, device_id: 0x00 }.into()),
        ))
        .enable_bank(1, bxcan::Fifo::Fifo0, Mask32::frames_with_ext_id(
          ExtendedId::new_unchecked(MessageId { device_type: DEVICE_TYPE_BROADCAST, manufacturer: MANUFACTURER_GRAPPLE, api_class: 0x00, api_index: 0x00, device_id: 0x00 }.into()),
          ExtendedId::new_unchecked(MessageId { device_type: 0xFF, manufacturer: 0xFF, api_class: 0x00, api_index: 0x00, device_id: 0x00 }.into()),
        ));
    }

    can_bus.enable_interrupts(Interrupts::TRANSMIT_MAILBOX_EMPTY | Interrupts::FIFO0_MESSAGE_PENDING);
    nb::block!(can_bus.enable_non_blocking()).unwrap();

    let (can_tx, can_rx, _) = can_bus.split();

    let mut delay = ctx.device.TIM3.delay_ms(&clocks);
    let mut rng = tiny_rng::Rng::from_seed(lasercan_common::get_serial_hash() as u64);

    // Delay for arbitration
    delay.delay_ms(rng.rand_range_u32(1, 50) * 20);

    // Perform arbitration
    let mut queue = VecDeque::with_capacity(16);

    let (reassemble_rx, reassemble_tx) = FragmentReassembler::new(1000, 8).split();

    enqueue(&&reassemble_tx, TaggedGrappleMessage::new(
      0,
      GrappleDeviceMessage::Broadcast(
        GrappleBroadcastMessage::DeviceInfo(GrappleDeviceInfo::ArbitrationRequest)
      )
    ), &mut queue);

    (
      SharedResources {
        device_id: 0,
        can_tx_queue: queue,
        status_led: status_led.erase(),
        reassemble_tx
      },
      LocalResources {
        can_rx, can_tx, flash,
        reassemble_rx,
        offset: 0,
        rng
      },
      init::Monotonics()
    )
  }

  #[idle(shared = [], local = [])]
  fn idle(_: idle::Context) -> ! {
    loop { }
  }

  #[task(binds = USB_HP_CAN_TX, priority = 13, local = [can_tx], shared = [can_tx_queue])]
  fn can_tx(mut ctx: can_tx::Context) {
    let tx = ctx.local.can_tx;

    tx.clear_interrupt_flags();
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

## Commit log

2023-12-16 Initial LaserCAN commit
    Implement LaserCAN - now working with RoboRIO
    First LaserCAN firmware release
    Update version to be the LaserCAN revision
    Remove firmware, put it elsewhere
    V2 Initial Design
    Add new layout
    Revision 2
    Working on firmware
    Implement most of the LaserCAN code
    Fix message format, message reassembly, get a full working prototype
    Slight updates to try and get the bootloader working
    Use RTIC for the bootloader
    Use 0x00 as device ID when upgrading firmware, so we don't flood other devices on the network
    Use constant-size firmware update parts
    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
    [LaserCAN-Board.kicad_pcb, LaserCAN-Board.kicad_sch]
2023-12-16 Update getting started guide to be transparent about power supply limits
2023-12-16 Update power supply note again
2023-12-17 Add PDF Schematic
    [LaserCAN-Board.kicad_sch]
2023-12-18 Update to v3.1 - Improved voltage regulation performance, improved ESD protection
    [LaserCAN-Board.kicad_pcb, LaserCAN-Board.kicad_sch]
2023-12-19 Update to new power regulation circuitry
    [LaserCAN-Board.kicad_pcb, LaserCAN-Board.kicad_sch]
2023-12-20 Add new power regulation, completely re-route board to accomodate
    [LaserCAN-Board.kicad_pcb, LaserCAN-Board.kicad_sch]
2023-12-20 Add new schematic
2023-12-20 Add LED feedback based on distance to target
2023-12-20 Modify the routing a little bit
    [LaserCAN-Board.kicad_pcb]
2023-12-20 Add a Transparent Rev4 LaserCAN
2023-12-21 Rev 4 updates
    [LaserCAN-Board.kicad_pcb, LaserCAN-Board.kicad_sch]
2023-12-21 Rev 4 - more updates
    [LaserCAN-Board.kicad_pcb, LaserCAN-Board.kicad_sch]
2023-12-21 Rev 4 Complete, barring any more review
    [LaserCAN-Board.kicad_pcb, LaserCAN-Board.kicad_sch]
2023-12-22 Rev 4 updates - NPTH, improved routing, BOM optimisation
    [LaserCAN-Board.kicad_pcb, LaserCAN-Board.kicad_sch]
2023-12-22 Slight part number change
    [LaserCAN-Board.kicad_sch]
2023-12-25 Add nops to avoid firmware flashing issues
    [main.rs]
2024-01-18 Start working on Rev5
    [LaserCAN-Board.kicad_pcb, LaserCAN-Board.kicad_sch]
2024-01-18 Rev 5 Updates
    [LaserCAN-Board.kicad_pcb]
2024-01-21 Slight changes
    [LaserCAN-Board.kicad_pcb, LaserCAN-Board.kicad_sch]
2024-01-21 Update to new libgrapplefrc version, add metadata to lasercan-impl
2024-04-01 Update to support new grplbndl flash method
    [LaserCAN-Board.kicad_pcb]
2024-06-19 Update build script to reflect connect-under-reset requirement for LaserCAN
